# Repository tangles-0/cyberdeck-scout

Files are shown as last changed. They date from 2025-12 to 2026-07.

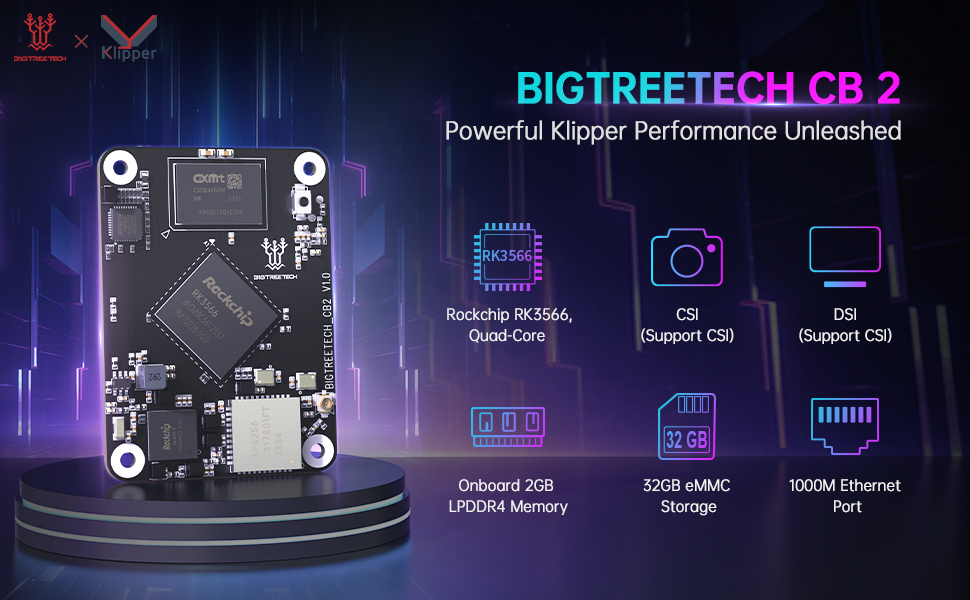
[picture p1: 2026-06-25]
Display Overlays/dsi-bigtreetech-cb2/wallpaper.jpg

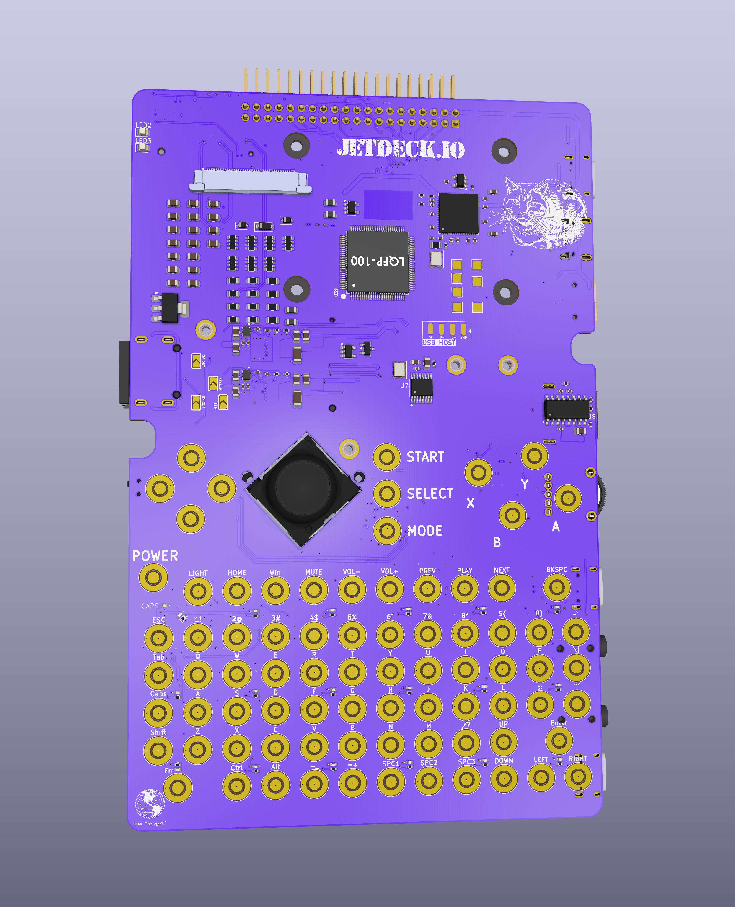
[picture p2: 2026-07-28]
PCB/cyberdeck/cyberdeck-a.png

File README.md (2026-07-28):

## JetDeck SCOUT - https://jetdeck.io

# Scout Cyberdeck

Repository contents:

- PCB design files
  - `/PCB/cyberdeck` current working PCB design file
  - `/PCB/cyberdeck-r1|r2 etc` snapshot of files sent for production
- USB PD sink EEPROM flash
  - `/Firmware/TPS25751` EEPROM images for the TPS25751 PD front-end
- Gamepad / mouse firmware
  - `/Firmware/gamepad-touch` RP2040 mbed sketch for the gamepad. reports HID Mouse, HID Gamepad, HID Touch Interface, and HID Battery to the host
- Keyboard firmware
  - `/Firmware/qmk/` drop this into your `qmk_firmware` folder and run `qmk flash -kb rii/518bt -km default` to flash the keyboard
- Bring-up / test / QA jig (PCB files TBA) and firmware
  - `/Firmware/esp32-bringup` 
- 3D casing design files
  - `/Casing CAD`
- Datasheets
  - `/Datasheets` for the major components used
- Display Overlays
  - `/Display Overlays` overlays for the DSI display used in testing
- Software
  - `/Software` will be used if any custom software is written

// #ifndef PIN_PA0
// #define PIN_PA0 11
// #endif
// #ifndef PIN_PA1
// #define PIN_PA1 8
// #endif
// #ifndef PIN_PA2
// #define PIN_PA2 9
// #endif
// #ifndef PIN_PA3
// #define PIN_PA3 10
// #endif
// #ifndef PIN_PA4
// #define PIN_PA4 0
// #endif
// #ifndef PIN_PA5
// #define PIN_PA5 1
// #endif
// #ifndef PIN_PA6
// #define PIN_PA6 2
// #endif
// #ifndef PIN_PA7
// #define PIN_PA7 3
// #endif
// #ifndef PIN_PB0
// #define PIN_PB0 7
// #endif
// #ifndef PIN_PB1
// #define PIN_PB1 6
// #endif
// #ifndef PIN_PB2
// #define PIN_PB2 5
// #endif
// #ifndef PIN_PB3
// #define PIN_PB3 4
// #endif

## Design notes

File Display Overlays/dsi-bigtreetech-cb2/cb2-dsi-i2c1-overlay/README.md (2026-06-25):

# CB2 DSI1 I2C1 Display Overlay

This overlay enables the BIGTREETECH CB2 DSI1 display path while moving the Raspberry Pi 7-inch display control MCU and FT5406-compatible touch controller from the stock CB2 I2C2 pins to I2C1.

Use this for carrier boards where the display I2C lines are:

- SCL: CM pin 35, `GPIO0_B3`
- SDA: CM pin 26, `GPIO0_B4`

The overlay was tested on the CB2 Debian 12 kernel `6.1.115-btt-rk35xx`.

Expected I2C devices after boot:

- `1-0045`: display MCU/backlight
- `1-0038`: FT5406-compatible touch controller

## Files

- `cb2-dsi-i2c1-rpi7.dts`: editable device tree overlay source.
- `cb2-dsi-i2c1-rpi7.dtbo`: compiled overlay to install on the CB2.
- `install.sh`: installs the overlay and updates `/boot/armbianEnv.txt`.

## Install

Copy this folder to the CB2, then run:

```bash
cd cb2-dsi-i2c1-overlay
sudo ./install.sh
sudo reboot
```

The installer:

- Creates `/boot/overlay-user/`.
- Copies `cb2-dsi-i2c1-rpi7.dtbo` into it.
- Backs up `/boot/armbianEnv.txt`.
- Clears `overlays=` so the stock `dsi` overlay does not also enable the wrong I2C2 nodes.
- Sets `user_overlays=cb2-dsi-i2c1-rpi7`.

The relevant `/boot/armbianEnv.txt` lines should look like:

```ini
overlays=
user_overlays=cb2-dsi-i2c1-rpi7
```

## Build

If you edit the source, rebuild the compiled overlay with:

```bash
dtc -@ -I dts -O dtb -o cb2-dsi-i2c1-rpi7.dtbo cb2-dsi-i2c1-rpi7.dts
```

Install `device-tree-compiler` first if `dtc` is missing.

## Verify

After reboot:

```bash
ls /sys/class/drm
dmesg | grep -Ei 'dsi|panel|i2c|touch|raspberry'
```

You should see a DSI connector such as `card0-DSI-1`, and the old failing probes on I2C2 (`2-0045`, `2-0038`) should be gone.

Touch should appear as an input device:

```bash
grep -E 'Name=|Handlers=' /proc/bus/input/devices
```

The working setup reports a device similar to `1-0038 generic ft5x06`.

## Rollback

If the board does not boot/display correctly, restore the backup from SSH or serial:

```bash
sudo cp /boot/armbianEnv.txt.pre-cb2-dsi-i2c1-rpi7 /boot/armbianEnv.txt
sudo reboot
```

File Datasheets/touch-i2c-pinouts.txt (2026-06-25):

Current driver / OLED display i2c pinout

1 SCL
2 SDA
3 INT
4 GND
5 VDD
6 RST

Large pitch display i2c pinout

1 GND
2 SDA
3 SCL
4 RST
5 INT
6 VDD3.3V

blk grn blu yel wht red

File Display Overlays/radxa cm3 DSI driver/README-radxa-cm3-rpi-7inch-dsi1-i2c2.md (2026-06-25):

# Radxa CM3 Raspberry Pi 7-inch DSI Overlay

This folder contains patched Radxa CM3 overlays for a Raspberry Pi 7-inch-touch-compatible DSI panel on a CM5-wired carrier board.

The shipped CM3 `disp1` overlay enables `dsi1`, but places the panel control/touch devices on `i2c0`. These patched overlays move the control/touch bus to `i2c2` using the CM3 `i2c2m1_xfer` pinmux.

Recommended overlay for the DSI panel:

```text
radxa-cm3-rpi-cm4-7inch-touchscreen-disp1-i2c2.dtbo
```

Experimental HDMI-enabled overlay:

```text
radxa-cm3-rpi-cm4-7inch-touchscreen-disp1-i2c2-hdmi.dtbo
```

The HDMI-enabled overlay leaves HDMI connected at the kernel/DRM level, with HDMI routed via `vp0` and DSI routed via `vp1`. On the tested Radxa CM3 image, KDE/X11 reports two extended displays, but both physical panels show the same scanout content. Treat this overlay as experimental or mirrored-output only, not a confirmed independent dual-display setup.

## Install

Copy the overlay to the Radxa:

```sh
scp radxa-cm3-rpi-cm4-7inch-touchscreen-disp1-i2c2.dtbo radxa@192.168.1.129:/tmp/
```

Install it into `/boot/dtbo`:

```sh
ssh radxa@192.168.1.129
sudo install -o root -g root -m 0644 /tmp/radxa-cm3-rpi-cm4-7inch-touchscreen-disp1-i2c2.dtbo /boot/dtbo/
```

Back up the boot config:

```sh
stamp=$(date +%Y%m%d-%H%M%S)
sudo cp -a /etc/default/u-boot "/etc/default/u-boot.bak.$stamp"
sudo cp -a /boot/extlinux/extlinux.conf "/boot/extlinux/extlinux.conf.bak.$stamp"
```

Add this to `/etc/default/u-boot`:

```sh
U_BOOT_FDT_OVERLAYS="radxa-cm3-rpi-cm4-7inch-touchscreen-disp1-i2c2.dtbo"
```

Regenerate the bootloader config and reboot:

```sh
sudo u-boot-update
sudo reboot
```

## Verify

After reboot, these checks should show the panel bound on `dsi1` and the touch/control devices bound on `i2c2`:

```sh
tr '\0' '\n' </proc/device-tree/dsi@fe070000/status
tr '\0' '\n' </proc/device-tree/i2c@fe5b0000/status
ls /sys/bus/i2c/devices/2-0030 /sys/bus/i2c/devices/2-0038 /sys/bus/i2c/devices/2-0045
cat /sys/class/drm/card0-DSI-1/status
cat /sys/class/drm/card0-DSI-1/modes
grep -A8 'Name="fts_ts"' /proc/bus/input/devices
```

Expected results:

```text
dsi1 status: okay
i2c2 status: okay
DRM connector: card0-DSI-1 connected
DSI mode: 800x480
touch input: fts_ts on i2c-2 address 0x38
panel MCU: rockpi_mcu on i2c-2 address 0x45
optional touch/client node: chipone_icn8505 on i2c-2 address 0x30
```

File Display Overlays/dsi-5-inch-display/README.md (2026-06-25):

# 5-inch DSI ILI9881C Overlay

This directory contains the working overlay for the 5-inch 720x1280 DSI display on a Raspberry Pi CM5.
Sold as "Surenoo" brand on Aliexpress: https://www.aliexpress.com/item/1005006436051194.html
Listed as a WKS50HD002-WCT from supplier WKS Technology Co., LTD according to datasheet

## Files

- `ili9881c.dtbo` - compiled overlay to copy onto the Pi
- `ili9881c-overlay.dts` - source used to build the overlay

## Install

Copy the compiled overlay to:

```bash
sudo cp ili9881c.dtbo /boot/firmware/overlays/ili9881c.dtbo
```

Then enable it in `/boot/firmware/config.txt`:

```ini
[cm5]
dtoverlay=ili9881c
```

Keep other DSI panel overlays disabled at the same time, for example:

```ini
#dtoverlay=vc4-kms-dsi-7inch,dsi1
#dtoverlay=vc4-kms-dsi-ili9881-7inch
```

## Build

```bash
dtc -@ -I dts -O dtb -o ili9881c.dtbo ili9881c-overlay.dts
```

The known-good panel compatible is:

```dts
compatible = "crystalfontz,cfaf7201280a0_050tx";
```

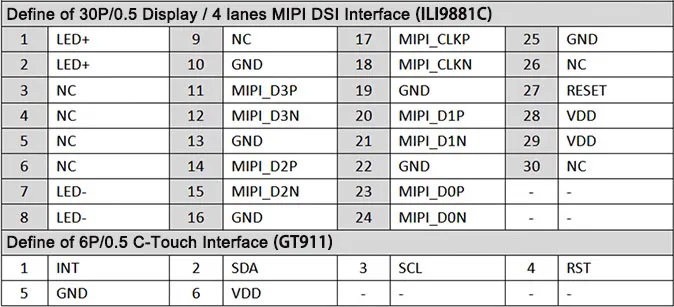
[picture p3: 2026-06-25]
Display Overlays/dsi-5-inch-display/5inch display pinout.png

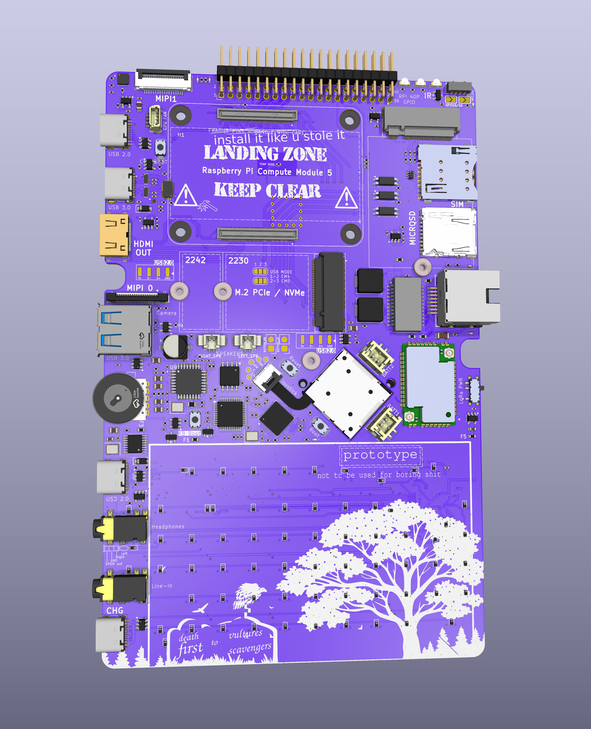
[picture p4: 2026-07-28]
PCB/cyberdeck/cyberdeck-b.png

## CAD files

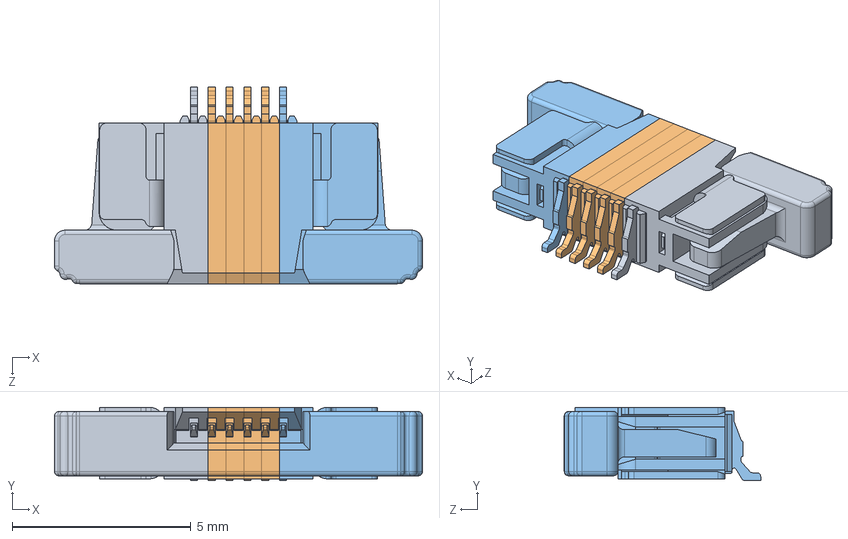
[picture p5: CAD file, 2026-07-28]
PCB-Resources/models/F32Q-1A7H1-11006--3DModel-STEP-56544.STEP
10.3 x 2.05 x 5.50 mm
F32Q_L.STEP
F32Q_M.STEP x 4
F32Q_R.STEP

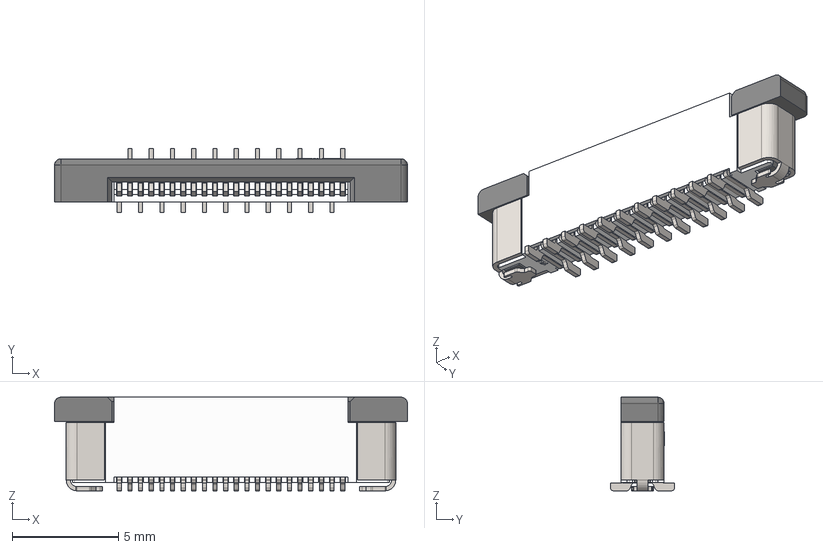
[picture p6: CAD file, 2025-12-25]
PCB/cyberdeck-compact/EASYEDA_MODELS/FPC-SMD_22P-P1.00_AFC11-S22ICC-00.step
16.6 x 3.00 x 4.40 mm

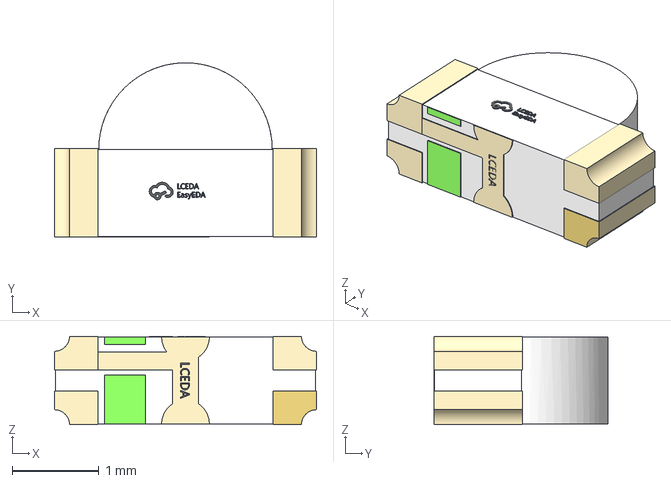
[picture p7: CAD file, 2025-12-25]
PCB/usb-cart/EASYEDA_MODELS/LED-ARRAY-SMD_3P-L3.0-W2.0-H1.0.step
3.02 x 2.01 x 1.02 mm

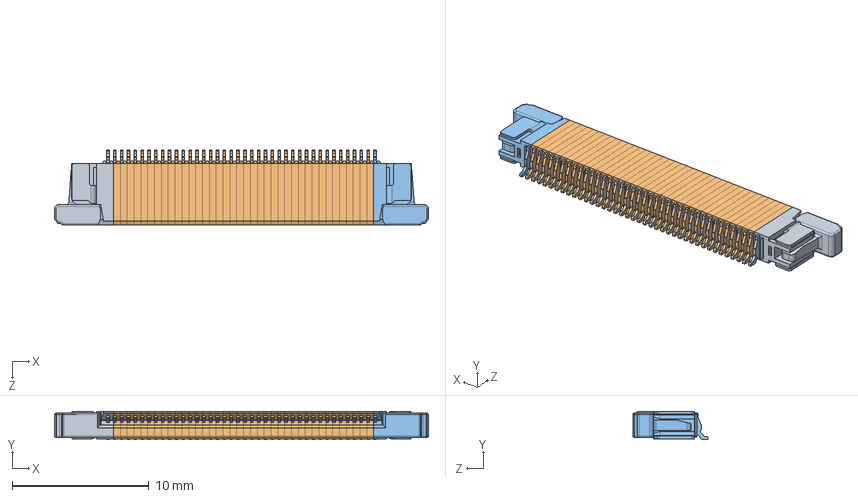
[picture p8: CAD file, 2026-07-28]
PCB-Resources/models/F32Q-1A7H1-11040--3DModel-STEP-56544.STEP
27.3 x 2.05 x 5.50 mm
F32Q_L.STEP
F32Q_M.STEP x 38
F32Q_R.STEP

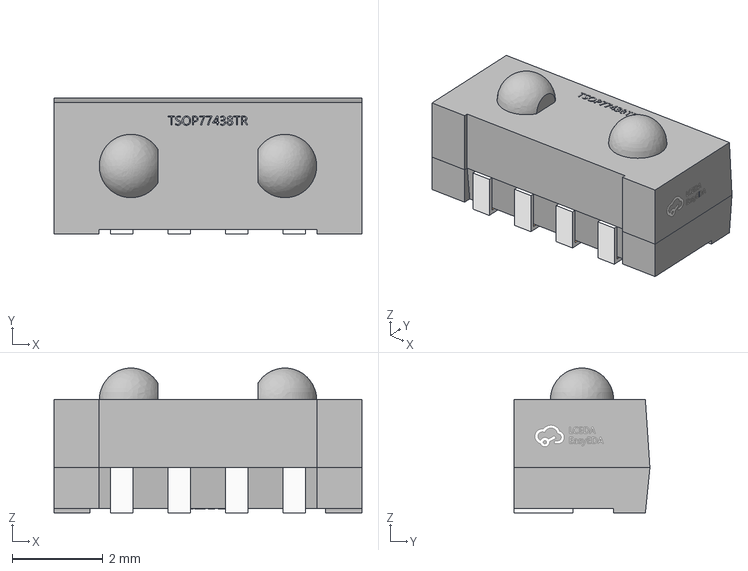
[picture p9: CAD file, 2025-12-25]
PCB/cyberdeck-compact/EASYEDA_MODELS/SENSOR-SMD_TSOP77438TR.step
6.80 x 3.00 x 3.20 mm

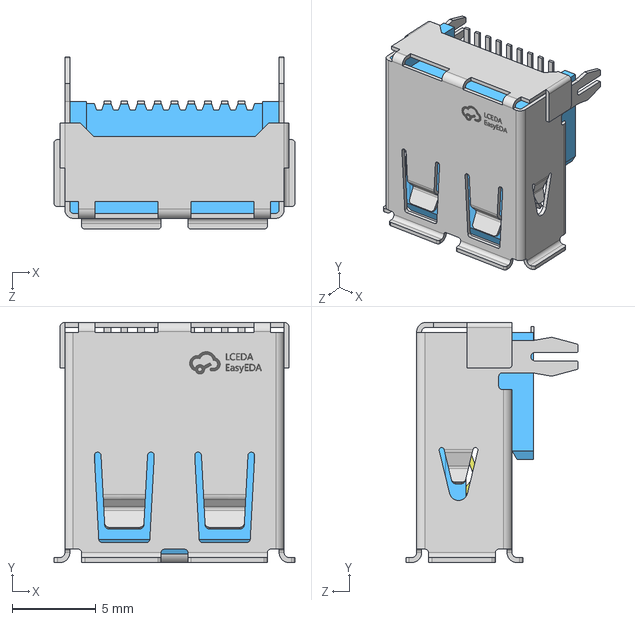
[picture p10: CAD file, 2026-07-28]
PCB-Resources/models/USB-3.0-SMD_U-A-39DS-Y-1.step
14.4 x 14.4 x 10.3 mm

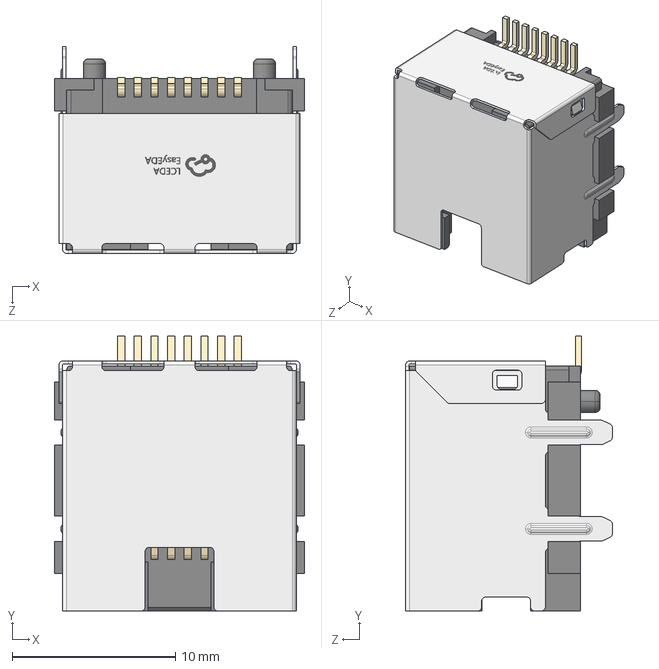
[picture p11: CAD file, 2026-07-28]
PCB-Resources/models/RJ45-SMD_RJ-064.step
15.3 x 16.8 x 12.7 mm

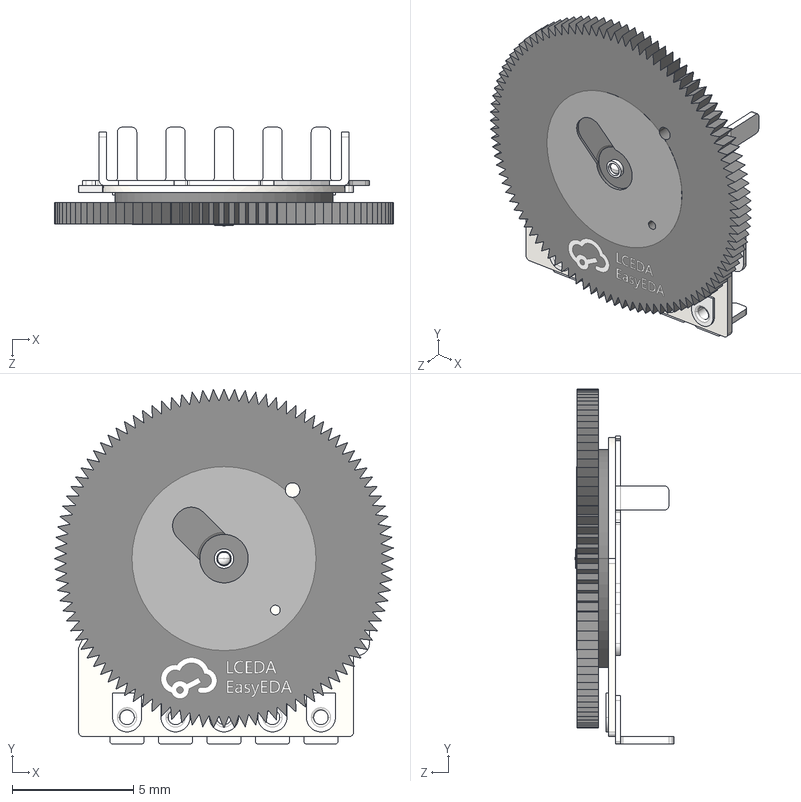
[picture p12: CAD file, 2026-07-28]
PCB-Resources/models/RES-TH_RK10J12E002L.step
14.0 x 14.6 x 4.07 mm

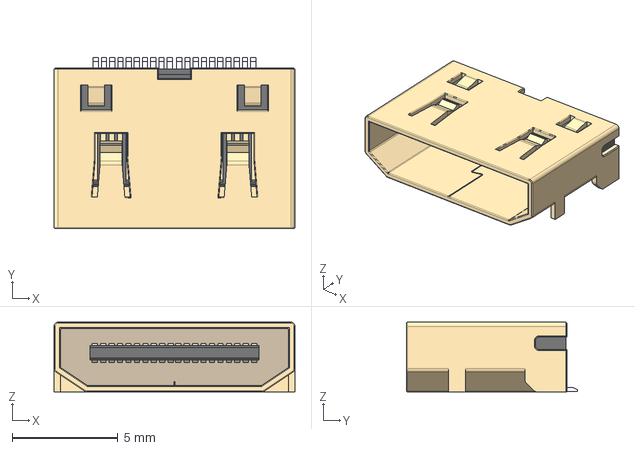
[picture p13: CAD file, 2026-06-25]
PCB-Resources/models/Mini_HDMI_Type-C.step
11.4 x 8.10 x 3.30 mm

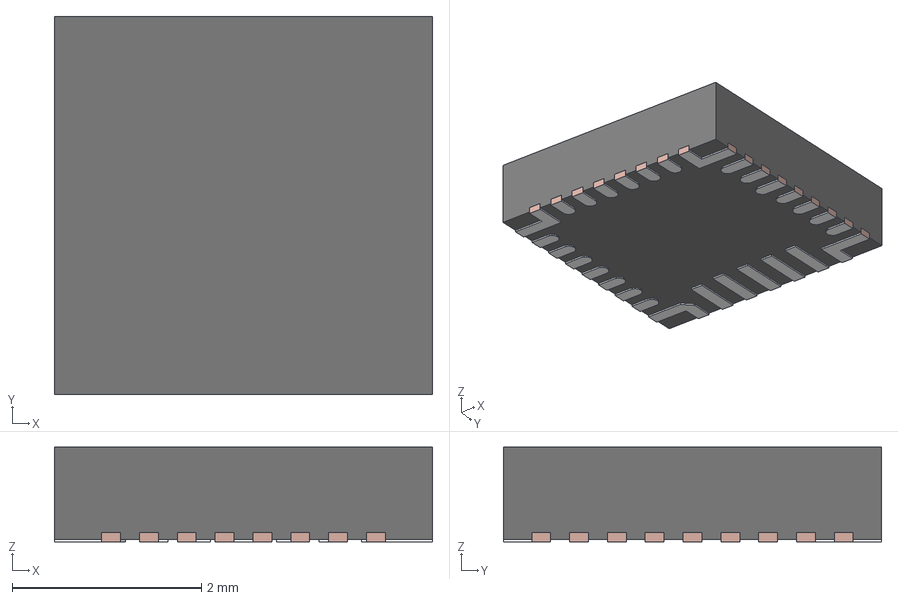
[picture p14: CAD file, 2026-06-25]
PCB-Resources/models/RQM0029A.stp
4.00 x 4.00 x 1.00 mm
FRAME
MOLD

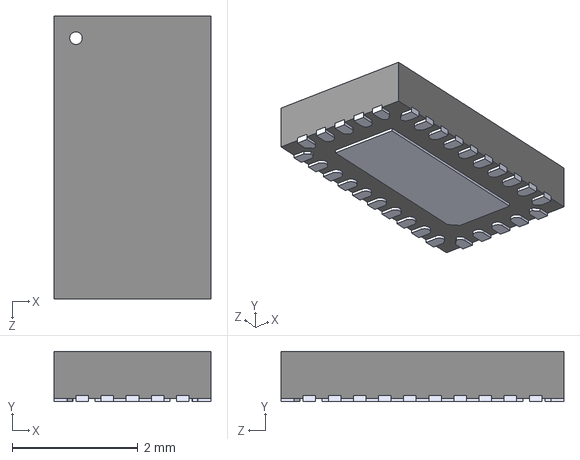
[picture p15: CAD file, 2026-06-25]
PCB-Resources/models/HD3SS3220IRNHT.step
2.50 x 0.8 x 4.50 mm

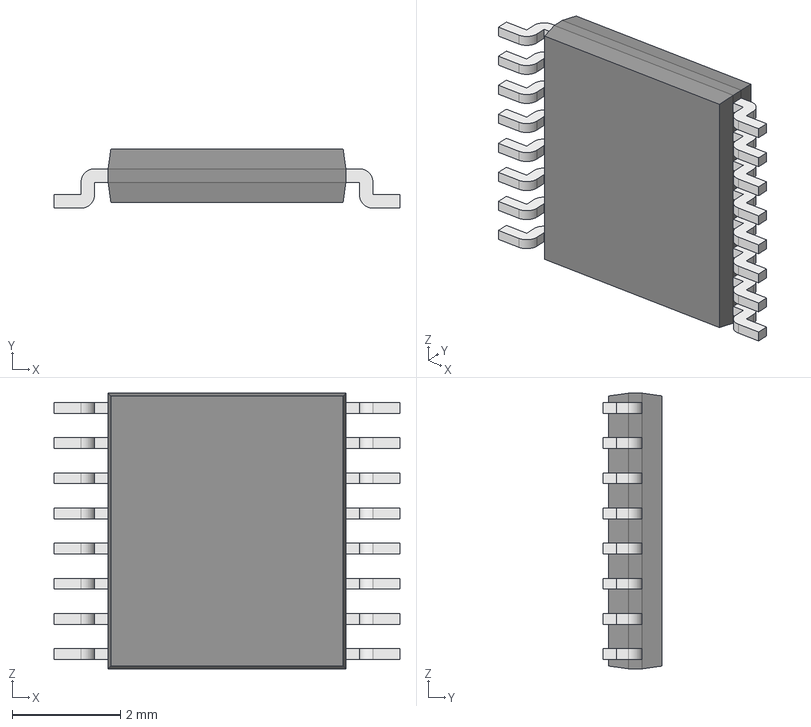
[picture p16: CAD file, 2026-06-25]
PCB-Resources/models/S-8254AAWFT-TB-G.step
6.40 x 1.10 x 5.10 mm
Body001 (Mirror #1) x 8
XY-plane x 12
X-axis x 12

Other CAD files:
PCB-Resources/models/1-2199119-5.step
PCB-Resources/models/1000base-t-magnetics.stp
PCB-Resources/models/10164227-1001a1rlf.stp
PCB-Resources/models/10164227-1004A1RLF.step
PCB-Resources/models/2-1734839-0.stp
PCB-Resources/models/2199119-3.step
PCB-Resources/models/2199230-3.stp
PCB-Resources/models/4_3inch-dsi-lcd-V1.stp
PCB-Resources/models/7498111120R--3DModel-STEP-56544.STEP
PCB-Resources/models/AFC01-S40FCA-00.step
PCB-Resources/models/AFC07-S05FCA-00.stp
PCB-Resources/models/AFC07-S22FCA-00.stp
PCB-Resources/models/AFC07-S30FCA-00.stp
PCB-Resources/models/B2B-PH-SM4-TB--3DModel-STEP-418109.STEP
PCB-Resources/models/BM04B-SRSS-TB.step
PCB-Resources/models/BQ25792RQMR.step
PCB-Resources/models/BQ76905RGRR.step
PCB-Resources/models/DM3AT-SF-PEJM5.step
PCB-Resources/models/FPC-5.stp
PCB-Resources/models/FTE-121-01-G-DH-K.stp
PCB-Resources/models/HR961160C.step
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

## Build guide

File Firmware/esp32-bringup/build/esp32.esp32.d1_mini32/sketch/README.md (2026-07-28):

#line 1 "/media/nvme_raid0/mPC/cyberdeck-scout/Firmware/esp32-bringup/README.md"
# Unified ESP32 service

Single sketch combining:

- **BQ76905** — negotiated I2C control with the ATtiny404. The Tiny owns the BQ by default, then hands controller role to the ESP when it detects the ESP discovery target.
- **TPS25751 + BQ25792** — JSON snapshot on **I2Ct** only (TPS as I2C target + BQ25792). The ESP does **not** use I2Cc for monitoring; I2Cc is controller-side on your board and is not where TPS status is read.
- **Flashing** — browser upload to LittleFS staging (`/stg_eeprom.bin`, `/stg_attiny.bin`), then background jobs:
  - **EEPROM** on **I2Cc** (AT24). **Power TPS25751 down** before starting — firmware temporarily remaps the second hardware I2C peripheral from I2Ct pins to I2Cc pins for the duration of the job, then restores I2Ct for `/api/charger`.
  - **ATtiny404** over UART-mode **UPDI** (same framing ideas as `jtag2updi`).

## I2C wiring model

| Bus | Role |
|---|---|
| First `TwoWire(0)` | BQ76905 / ATtiny404 shared bus. ESP starts as discovery target `ESP_BQ_DISCOVERY_ADDR`, then becomes controller after Tiny handoff |
| Second `TwoWire(1)` @ **I2Ct** pins | TPS25751 target + BQ25792 — **monitoring** |
| Same peripheral @ **I2Cc** pins | EEPROM programming **only** while TPS is off |

Current defaults use GPIO **25/26** for **I2Ct** charger monitoring and GPIO **18/19** for the optional **I2Cc** EEPROM-flash remap. Adjust **`PIN_I2C_I2CT_*`** and **`PIN_I2C_I2CC_*`** in [config.h](config.h) to match your wiring before building.

## Configure before build

Edit **[config.h](config.h)**:

- `WIFI_SSID` / `WIFI_PASS`
- `PIN_I2C_BQ_*` — shared BQ76905 / ATtiny404 bus. Default firmware starts the ESP as an I2C discovery target at `0x42`; after handoff, the ESP becomes BQ controller and pings the Tiny target at `0x43`.
- `PIN_I2C_I2CT_*` — charger / PD monitor (TPS + BQ25792).
- `PIN_I2C_I2CC_*` — EEPROM (flash job only).
- `PIN_UPDI_RX` / `PIN_UPDI_TX` — jtag2updi-style UPDI wiring: RX direct to target UPDI, TX to target UPDI through a series resistor; **115200 8E2** after double-break by default.

## Build / upload

Arduino IDE or CLI, ESP32 core, board such as **ESP32 Dev Module** (`esp32:esp32:esp32`).

Partition scheme: default usually suffices; LittleFS is created with `LittleFS.begin(true)` on first boot.

## Web UI

Open device IP in a browser. Tabs:

1. **BQ76905** — telemetry + tiles from direct ESP reads after handoff. Before handoff, buttons are disabled because the Tiny still owns BQ configuration and balancing. Tiny probes the ESP every ~3 s, tells it to become controller, then listens as a target for 500 ms ESP pings. The first ping gets an 8 s startup grace window; after pings are established, a >1 s miss returns the Tiny to BQ master mode, reconfigures the BQ, and resumes ESP discovery.
2. **Charger / PD** — formatted `/api/charger` JSON (or a suspended message while an EEPROM job holds the bus).
3. **Flash** — upload EEPROM / ATTiny binaries, then **Start**; poll `/api/flash/status`.

## Limitations

- **ATTiny UPDI** path is a focused application programmer (no Arduino-IDE JTAG2 bridge, no fuse writes). Target is **ATtiny404** (4 KB flash) via `ATTINY_FLASH_*` in `config.h`. Wire the ESP32 like the working Pro Micro setup: RX direct to the ATtiny UPDI pin and TX through the resistor. On enter-prog failure, `/api/flash/status` includes `updi_asi_status` (raw `ASI_System_Status`; `0xFF` usually means no UPDI reply).
- During EEPROM programming the charger tab may show `charger_monitor_suspended` — normal until the job finishes and I2Ct is restored.

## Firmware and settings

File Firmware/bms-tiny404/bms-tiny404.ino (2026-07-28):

// ATtiny404 BQ76905 host: configuration, power control, indicators, and host cell balancing.
// Requires megaTinyCore in Arduino IDE or arduino-cli.
// I2C to the BQ is bit-banged on PA1/PA2: the 404 (tinyAVR 0-series) has no
// alternate TWI pin position, and its hardware TWI pins (PB0/PB1) drive LEDs.

#define DEBUG 1
#define ENABLE_SHIP_BUTTON 0

// test swaps
static const uint8_t LED_PIN = PIN_PB3;
static const uint8_t BATT_LEVEL1_LED_PIN = PIN_PA4;

// rev 1b layout
static const uint8_t PWR_BUTTON_PIN = PIN_PA5;
static const uint8_t SHIP_BUTTON_PIN = PIN_PA6;
static const uint8_t PWR_CONTROL_PIN = PIN_PA3;
//static const uint8_t LED_PIN = PIN_PA4;
static const uint8_t CM5_SOFT_PWR_OUT = PIN_PA7;

//static const uint8_t BATT_LEVEL1_LED_PIN = PIN_PB3;
static const uint8_t BATT_LEVEL2_LED_PIN = PIN_PB2;
static const uint8_t BATT_LEVEL3_LED_PIN = PIN_PB1;
static const uint8_t BATT_LEVEL4_LED_PIN = PIN_PB0;

// BQ7690x I2C address
static const uint8_t BQ_ADDR = 0x08;

// Subcommand and data registers
static const uint8_t REG_SUBCMD = 0x3E;
static const uint8_t REG_SUBCMD_DATA = 0x60;
static const uint8_t REG_SAFETY_STATUS_A = 0x03;
static const uint8_t REG_BATTERY_STATUS = 0x12;
static const uint8_t REG_ALARM_RAW_STATUS = 0x64;
// static const uint8_t REG_FET_CONTROL = 0x68;
// static const uint8_t REGOUT_CONTROL = 0x69;
// static const uint8_t REGOUT_REG_EN = (1u << 3);

// Command-only subcommands
static const uint16_t SET_CFGUPDATE = 0x0090;
static const uint16_t EXIT_CFGUPDATE = 0x0092;
static const uint16_t DEEPSLEEP = 0x000F;
static const uint16_t EXIT_DEEPSLEEP = 0x000E;
#if ENABLE_SHIP_BUTTON
static const uint16_t SHUTDOWN = 0x0010;
#endif
// static const uint16_t FET_ENABLE = 0x0022;
// static const uint16_t SLEEP_DISABLE = 0x009A; // not needed - sleep mode is autonomous and desirable.

// Host-controlled balancing active-cells subcommand (requires payload bitmask).
// Required to be re-issued every ~18s; BQ aborts after ~20s for safety.
static const uint16_t START_BALANCE = 0x0083; 

// Configuration register addresses
static const uint16_t VcellMode = 0x901B;
static const uint16_t DefaultAlarmMask = 0x901C;
static const uint16_t FETOptions = 0x901E;
static const uint16_t EnabledProtectionsA = 0x9024;
static const uint16_t EnabledProtectionsB = 0x9025;
static const uint16_t BalancingConfiguration = 0x9020;
static const uint16_t BalancingMinTempThreshold = 0x9021;
static const uint16_t BalancingMaxTempThreshold = 0x9022;
static const uint16_t BalancingMaxInternalTemp = 0x9023;
static const uint16_t CellUndervoltageProtectionThreshold = 0x902E;
static const uint16_t CellUndervoltageProtectionDelay = 0x9030;
static const uint16_t CellUndervoltageProtectionRecoveryHysteresis = 0x9031;
static const uint16_t CellOvervoltageProtectionThreshold = 0x9032;
static const uint16_t CellOvervoltageProtectionDelay = 0x9034;
static const uint16_t CellOvervoltageProtectionRecoveryHysteresis = 0x9035;

// Cell voltage registers (for host balancing decisions only)
static const uint8_t REG_CELL1_VOLTAGE = 0x14;
static const uint8_t REG_CELL2_VOLTAGE = 0x16;

// Button, power-control, and indicator timings (ms)
static const uint16_t SHORT_PRESS_MIN_MS = 80;
static const uint16_t LONG_PRESS_MS = 3000;
static const uint16_t CM5_SOFT_PRESS_MS = 300;
static const uint16_t POWER_SOFT_PRESS_ARM_MS = 15000;
static const uint8_t POWER_LED_IDLE_BREATH_STEP_MS = 18;
static const uint8_t FAST_LED_BREATH_STEP_MS = 5;
static const uint16_t STATUS_LED_BLINK_MS = 120;
static const uint16_t SHIP_LED_BLINK_MS = 100;
static const uint16_t PROTECTION_LED_MIN_MS = 3000;

static const uint8_t POWER_LED_ON_DUTY = 180;
static const uint8_t POWER_LED_BREATH_MIN_DUTY = 5;
static const uint8_t POWER_LED_BREATH_MAX_DUTY = 100;
static const uint8_t BATT_LED_BREATH_MIN_DUTY = 5;
static const uint8_t BATT_LED_BREATH_MAX_DUTY = 180;

static const uint16_t ALARM_RAW_CB = (1u << 8);
static const uint8_t SAFETY_STATUS_A_CUV = (1u << 6);
static const uint8_t SAFETY_STATUS_A_COV = (1u << 7);

// 2S Li-ion display thresholds. LED1 is the low/end-of-pack indicator.
static const uint16_t CELL_UV_THRESHOLD_MV = 3000;
static const uint16_t CELL_OV_THRESHOLD_MV = 4200;
static const uint16_t LOW_BATT_WARN_CELL_MV = 3150;
static const uint16_t BATT_LED1_PACK_MV = 6100;
static const uint16_t BATT_LED2_PACK_MV = 6900;
static const uint16_t BATT_LED3_PACK_MV = 7400;
static const uint16_t BATT_LED4_PACK_MV = 7900;

// Host balancing poll interval
static const uint16_t BALANCE_POLL_PERIOD_MS = 100;

// Host balancing (START_BALANCE): not gated on charge current or device power state.
// Balance whichever cell is higher once the voltage and imbalance thresholds are met.
static const uint16_t BALANCE_MIN_ANY_CELL_MV = 3100;
static const uint16_t BALANCE_MIN_DELTA_MV = 20;
static const uint16_t BALANCE_RETRIGGER_MS = 18000; // BQ balancing command timeout is about 20s
static const uint16_t BQ_CONFIG_RETRY_MS = 1000;

#if DEBUG
static void debugBegin() {
  pinModeFast(BATT_LEVEL2_LED_PIN, OUTPUT);
  USART0.BAUD = (uint16_t)((4UL * F_CPU) / 115200);
  USART0.CTRLC = USART_CHSIZE_8BIT_gc;
  USART0.CTRLB = USART_TXEN_bm;
}

static void debugChar(char c) {
  while (!(USART0.STATUS & USART_DREIF_bm)) {}
  USART0.TXDATAL = c;
}

static void debugUint(uint16_t value) {
  char buf[5];
  uint8_t i = 0;
  do {
    buf[i++] = (char)('0' + value % 10);
    value /= 10;
  } while (value != 0);
  while (i != 0) {
    debugChar(buf[--i]);
  }
}

static void debugNl() {
  debugChar('\n');
}
#else
#define debugBegin() do {} while (0)
#define debugChar(c) do {} while (0)
#define debugUint(v) do {} while (0)
#define debugNl() do {} while (0)
#endif

static uint8_t checksum(const uint8_t *data, uint8_t len) {
  uint16_t sum = 0;
  for (uint8_t i = 0; i < len; i++) {
    sum += data[i];
  }
  return (uint8_t)(0xFF & ~sum);
}

// Bit-banged open-drain I2C master on PA1 (SDA) / PA2 (SCL).
// The ATtiny404 is a tinyAVR 0-series part: its hardware TWI exists only on
// PB0/PB1 (no PORTMUX alternate position — that is a 1-series feature), but
// the board routes the BQ bus to PA1/PA2. External 10K pullups; lines are
// driven low by flipping DIR (OUT stays 0), released by tri-stating.
static const uint8_t I2C_SDA_bm = (1 << 1); // PA1
static const uint8_t I2C_SCL_bm = (1 << 2); // PA2

// Error codes kept compatible with Wire/debug protocol:
// 0 ok, 2 address NACK, 3 data NACK, 5 clock-stretch timeout.
static uint8_t lastI2cError = 0;

static inline void i2cDelay() { delayMicroseconds(4); } // ~100 kHz

static bool i2cSclRelease() {
  VPORTA.DIR &= ~I2C_SCL_bm;
  // Allow slave clock stretching, with a timeout so a dead bus can't hang us.
  for (uint16_t i = 0; i < 10000; i++) {
    if (VPORTA.IN & I2C_SCL_bm) {
      return true;
    }
  }
  lastI2cError = 5;
  return false;
}

static void i2cStart() {
  VPORTA.DIR &= ~I2C_SDA_bm;
  i2cSclRelease();
  i2cDelay();
  VPORTA.DIR |= I2C_SDA_bm;  // SDA low while SCL high = START
  i2cDelay();
  VPORTA.DIR |= I2C_SCL_bm;
}

static void i2cStop() {
  VPORTA.DIR |= I2C_SDA_bm;
  i2cDelay();
  i2cSclRelease();
  i2cDelay();
  VPORTA.DIR &= ~I2C_SDA_bm; // SDA released while SCL high = STOP
  i2cDelay();
}

// Returns true if the slave ACKed the byte.
static bool i2cWriteByte(uint8_t value) {
  for (uint8_t bit = 0; bit < 8; bit++) {
    if (value & 0x80) {
      VPORTA.DIR &= ~I2C_SDA_bm;
    } else {
      VPORTA.DIR |= I2C_SDA_bm;
    }
    value <<= 1;
    i2cDelay();
    if (!i2cSclRelease()) {
      return false;
    }
    i2cDelay();
    VPORTA.DIR |= I2C_SCL_bm;
  }

  VPORTA.DIR &= ~I2C_SDA_bm; // release for ACK bit
  i2cDelay();
  if (!i2cSclRelease()) {
    return false;
  }
  const bool acked = (VPORTA.IN & I2C_SDA_bm) == 0;
  i2cDelay();
  VPORTA.DIR |= I2C_SCL_bm;
  return acked;
}

static uint8_t i2cReadByte(bool ack) {
  uint8_t value = 0;
  VPORTA.DIR &= ~I2C_SDA_bm;
  for (uint8_t bit = 0; bit < 8; bit++) {
    i2cDelay();
    if (!i2cSclRelease()) {
      return 0xFF;
    }
    value = (uint8_t)(value << 1);
    if (VPORTA.IN & I2C_SDA_bm) {
      value |= 1;
    }
    i2cDelay();
    VPORTA.DIR |= I2C_SCL_bm;
  }

  if (ack) {
    VPORTA.DIR |= I2C_SDA_bm;
  }
  i2cDelay();
  if (!i2cSclRelease()) {
    return value;
  }
  i2cDelay();
  VPORTA.DIR |= I2C_SCL_bm;
  VPORTA.DIR &= ~I2C_SDA_bm;
  return value;
}

static void i2cInit() {
  VPORTA.OUT &= ~(I2C_SDA_bm | I2C_SCL_bm); // low when driven
  VPORTA.DIR &= ~(I2C_SDA_bm | I2C_SCL_bm); // released (pulled up) when idle
}

static uint8_t i2cWrite(uint8_t reg, const uint8_t *data, uint8_t len) {
  lastI2cError = 0;
  i2cStart();
  if (!i2cWriteByte((uint8_t)(BQ_ADDR << 1))) {
    if (lastI2cError == 0) {
      lastI2cError = 2;
    }
  } else if (!i2cWriteByte(reg)) {
    if (lastI2cError == 0) {
      lastI2cError = 3;
    }
  } else {
    for (uint8_t i = 0; i < len; i++) {
      if (!i2cWriteByte(data[i])) {
        if (lastI2cError == 0) {
          lastI2cError = 3;
        }
        break;
      }
    }
  }
  i2cStop();
  delay(2);
  return lastI2cError;
}

static bool i2cRead16(uint8_t reg, uint16_t *value) {
  lastI2cError = 0;
  i2cStart();
  if (!i2cWriteByte((uint8_t)(BQ_ADDR << 1)) || !i2cWriteByte(reg)) {
    if (lastI2cError == 0) {
      lastI2cError = 2;
    }
    i2cStop();
    return false;
  }

  i2cStart(); // repeated START
  if (!i2cWriteByte((uint8_t)((BQ_ADDR << 1) | 1))) {
    if (lastI2cError == 0) {
      lastI2cError = 2;
    }
    i2cStop();
    return false;
  }

  const uint8_t lsb = i2cReadByte(true);
  const uint8_t msb = i2cReadByte(false);
  i2cStop();
  if (lastI2cError != 0) {
    return false;
  }
  *value = (uint16_t)(msb << 8) | lsb;
  return true;
}

static uint8_t sendSubcommand(uint16_t cmd) {
  uint8_t buf[2] = { (uint8_t)(cmd & 0xFF), (uint8_t)(cmd >> 8) };
  return i2cWrite(REG_SUBCMD, buf, sizeof(buf));
}

static void writeConfig8(uint16_t addr, uint8_t value) {
  uint8_t payload[3] = {
    (uint8_t)(addr & 0xFF),
    (uint8_t)(addr >> 8),
    value
  };
  uint8_t cks = checksum(payload, sizeof(payload));
  uint8_t meta[2] = { cks, 0x05 };
  i2cWrite(REG_SUBCMD, payload, sizeof(payload));
  i2cWrite(REG_SUBCMD_DATA, meta, sizeof(meta));
}

static void writeConfig16(uint16_t addr, uint16_t value) {
  uint8_t payload[4] = {
    (uint8_t)(addr & 0xFF),
    (uint8_t)(addr >> 8),
    (uint8_t)(value & 0xFF),
    (uint8_t)(value >> 8)
  };
  uint8_t cks = checksum(payload, sizeof(payload));
  uint8_t meta[2] = { cks, 0x06 };
  i2cWrite(REG_SUBCMD, payload, sizeof(payload));
  i2cWrite(REG_SUBCMD_DATA, meta, sizeof(meta));
}

static bool bqCellBalancingActive = false;
static bool bqReadValid = false;
static uint16_t latestBatteryStatus = 0;
static bool bqConfigured = false;
static uint16_t latestCell1Mv = 0;
static uint16_t latestCell2Mv = 0;
static uint16_t protectionBlinkUntilMs = 0;
static uint8_t protectionBlinkFlags = 0;
static uint16_t lastBqConfigAttemptMs = 0;
#if DEBUG
static uint16_t lastDebugStatusMs = 0;
#endif

static bool devicePowerOn = false;
static uint16_t devicePowerOnStartedMs = 0;
static uint8_t powerLedBreathDuty = POWER_LED_BREATH_MIN_DUTY;
static int8_t powerLedBreathDirection = 1;
static uint16_t powerLedLastStepMs = 0;
static uint8_t battLedBreathDuty = BATT_LED_BREATH_MIN_DUTY;
static int8_t battLedBreathDirection = 1;
static uint16_t battLedLastStepMs = 0;
static uint16_t lastStatusBlinkMs = 0;
static bool statusBlinkOn = false;

static void writeActiveLowPwm(uint8_t pin, uint8_t duty) {
  analogWrite(pin, 255 - duty);
}

static uint8_t breathingDuty(uint8_t *duty, int8_t *direction, uint16_t *lastStepMs,
                             uint16_t now, uint8_t stepMs,
                             uint8_t minDuty, uint8_t maxDuty) {
  if ((uint16_t)(now - *lastStepMs) >= stepMs) {
    *lastStepMs = now;
    const int16_t nextDuty = (int16_t)(*duty) + *direction;
    if (nextDuty >= maxDuty) {
      *duty = maxDuty;
      *direction = -1;
    } else if (nextDuty <= minDuty) {
      *duty = minDuty;
      *direction = 1;
    } else {
      *duty = (uint8_t)nextDuty;
    }
  }
  return *duty;
}

static void releasePowerControl() {
  digitalWriteFast(PWR_CONTROL_PIN, HIGH);
  //pinModeFast(PWR_CONTROL_PIN, INPUT_PULLUP);
}

static void releaseCm5SoftPower() {
  digitalWriteFast(CM5_SOFT_PWR_OUT, HIGH);
  pinModeFast(CM5_SOFT_PWR_OUT, INPUT_PULLUP);
}

static void setBatteryLedsOff() {
  digitalWriteFast(BATT_LEVEL1_LED_PIN, HIGH);
#if !DEBUG
  digitalWriteFast(BATT_LEVEL2_LED_PIN, HIGH);
#endif
  digitalWriteFast(BATT_LEVEL3_LED_PIN, HIGH);
  digitalWriteFast(BATT_LEVEL4_LED_PIN, HIGH);
}

static void setDevicePower(bool on) {
  if (on) {
    if (!devicePowerOn) {
      devicePowerOnStartedMs = (uint16_t)millis();
    }
    pinModeFast(PWR_CONTROL_PIN, OUTPUT);
    digitalWriteFast(PWR_CONTROL_PIN, LOW);
    devicePowerOn = true;
    debugChar('P');
    debugChar('1');
    debugNl();
    return;
  }

  releasePowerControl();
  releaseCm5SoftPower();
  setBatteryLedsOff();
  devicePowerOn = false;
  debugChar('P');
  debugChar('0');
  debugNl();
}

static void startCm5SoftPowerPress() {
  if (!devicePowerOn) {
    return;
  }

  pinModeFast(CM5_SOFT_PWR_OUT, OUTPUT);
  digitalWriteFast(CM5_SOFT_PWR_OUT, LOW);
  delay(CM5_SOFT_PRESS_MS);
  releaseCm5SoftPower();
}

static void powerLedTask() {
  const uint16_t now = (uint16_t)millis();

  if (bqCellBalancingActive) {
    writeActiveLowPwm(LED_PIN, breathingDuty(&powerLedBreathDuty, &powerLedBreathDirection,
                                             &powerLedLastStepMs, now, FAST_LED_BREATH_STEP_MS,
                                             POWER_LED_BREATH_MIN_DUTY,
                                             POWER_LED_BREATH_MAX_DUTY));
  } else if (devicePowerOn) {
    writeActiveLowPwm(LED_PIN, POWER_LED_ON_DUTY);
  } else {
    writeActiveLowPwm(LED_PIN, breathingDuty(&powerLedBreathDuty, &powerLedBreathDirection,
                                             &powerLedLastStepMs, now, POWER_LED_IDLE_BREATH_STEP_MS,
                                             POWER_LED_BREATH_MIN_DUTY,
                                             POWER_LED_BREATH_MAX_DUTY));
  }
}

static uint8_t batteryLedCount() {
  if (!bqReadValid) {
    return 0;
  }

  const uint16_t packMv = latestCell1Mv + latestCell2Mv;
  if (packMv >= BATT_LED4_PACK_MV) {
    return 4;
  }
  if (packMv >= BATT_LED3_PACK_MV) {
    return 3;
  }
  if (packMv >= BATT_LED2_PACK_MV) {
    return 2;
  }
  if (packMv >= BATT_LED1_PACK_MV) {
    return 1;
  }
  return 0;
}

static bool lowBatteryWarningActive() {
  if (!bqReadValid) {
    return false;
  }

  return latestCell1Mv <= LOW_BATT_WARN_CELL_MV || latestCell2Mv <= LOW_BATT_WARN_CELL_MV;
}

static void batteryLedTask() {
  if (!devicePowerOn) {
    setBatteryLedsOff();
    return;
  }

  const uint16_t now = (uint16_t)millis();
  if ((uint16_t)(now - lastStatusBlinkMs) >= STATUS_LED_BLINK_MS) {
    lastStatusBlinkMs = now;
    statusBlinkOn = !statusBlinkOn;
  }
  if (protectionBlinkFlags != 0 && (int16_t)(now - protectionBlinkUntilMs) >= 0) {
    protectionBlinkFlags = 0;
  }
  const bool showUnderVoltage = (protectionBlinkFlags & SAFETY_STATUS_A_CUV) != 0;
  const bool showOverVoltage = (protectionBlinkFlags & SAFETY_STATUS_A_COV) != 0;

  if (showUnderVoltage || showOverVoltage) {
    digitalWriteFast(BATT_LEVEL1_LED_PIN, showUnderVoltage && statusBlinkOn ? LOW : HIGH);
#if !DEBUG
    digitalWriteFast(BATT_LEVEL2_LED_PIN, showUnderVoltage && statusBlinkOn ? LOW : HIGH);
#endif
    digitalWriteFast(BATT_LEVEL3_LED_PIN, showOverVoltage && statusBlinkOn ? LOW : HIGH);
    digitalWriteFast(BATT_LEVEL4_LED_PIN, showOverVoltage && statusBlinkOn ? LOW : HIGH);
    return;
  }

  if (lowBatteryWarningActive()) {
    writeActiveLowPwm(BATT_LEVEL1_LED_PIN, breathingDuty(&battLedBreathDuty, &battLedBreathDirection,
                                                        &battLedLastStepMs, now, FAST_LED_BREATH_STEP_MS,
                                                        BATT_LED_BREATH_MIN_DUTY,
                                                        BATT_LED_BREATH_MAX_DUTY));
#if !DEBUG
    digitalWriteFast(BATT_LEVEL2_LED_PIN, HIGH);
#endif
    digitalWriteFast(BATT_LEVEL3_LED_PIN, HIGH);
    digitalWriteFast(BATT_LEVEL4_LED_PIN, HIGH);
    return;
  }

  const uint8_t litCount = batteryLedCount();
  digitalWriteFast(BATT_LEVEL1_LED_PIN, litCount >= 1 ? LOW : HIGH);
#if !DEBUG
  digitalWriteFast(BATT_LEVEL2_LED_PIN, litCount >= 2 ? LOW : HIGH);
#endif
  digitalWriteFast(BATT_LEVEL3_LED_PIN, litCount >= 3 ? LOW : HIGH);
  digitalWriteFast(BATT_LEVEL4_LED_PIN, litCount >= 4 ? LOW : HIGH);
}

#if ENABLE_SHIP_BUTTON
static void enterShipMode() {
  sendSubcommand(SHUTDOWN);
  sendSubcommand(SHUTDOWN);

  setDevicePower(false);
  while (true) {
    digitalWriteFast(LED_PIN, LOW);
    delay(SHIP_LED_BLINK_MS);
    digitalWriteFast(LED_PIN, HIGH);
    delay(SHIP_LED_BLINK_MS);
  }
}
#endif

static bool bqPresent() {
  lastI2cError = 0;
  i2cStart();
  if (!i2cWriteByte((uint8_t)(BQ_ADDR << 1)) && lastI2cError == 0) {
    lastI2cError = 2;
  }
  i2cStop();
  return lastI2cError == 0;
}

static bool configureBq76905() {
  if (!bqPresent()) {
    // N<err> <pinlevels>: pinlevels bit0=SDA, bit1=SCL (3 = bus idle high).
    debugChar('N');
    debugUint(lastI2cError);
    debugChar(' ');
    debugChar((char)('0' + ((VPORTA.IN >> 1) & 0x03)));
    debugNl();
    return false;
  }

  sendSubcommand(SET_CFGUPDATE);
  delay(10);

  // 2S Li-ion defaults (VcellMode uses 0x00 for 2-series)
  writeConfig8(VcellMode, 0x02);

  // Enable autonomous FET control and allow CHG FET in SLEEP mode.
  // Bit map (Table 12-8): SLEEPCHG=bit4, SFET=bit3, FET_EN=bit2.
  writeConfig8(FETOptions, 0x1C);
  //writeConfig8(FETOptions, 0x04);

  // Enable only CUV/COV safety protections.
  // SafetyStatusA bit mapping uses COV=bit7, CUV=bit6 -> mask 0xC0.
  // Use 8-bit writes here because EnabledProtectionsA/B are 1-byte fields.
  writeConfig8(EnabledProtectionsA, 0xC0);
  writeConfig8(EnabledProtectionsB, 0x00);
  // Cell balancing settings:
  // - CB_NO_CMD=0 (allow CB_ACTIVE_CELLS host command), CBDLY=1ms (0x02 default)
  // - very permissive balance temperature window during bring-up
  writeConfig8(BalancingConfiguration, 0x02);
  writeConfig8(BalancingMinTempThreshold, 0xFF);
  writeConfig8(BalancingMaxTempThreshold, 0x00);
  writeConfig8(BalancingMaxInternalTemp, 110);
  // Debug-friendly: enable all alarm sources so AlarmStatus can latch SSA/SSB
  // and other events for host visibility.
  writeConfig16(DefaultAlarmMask, 0xFFFF);

  // Typical 2S Li-ion per-cell thresholds.
  // Thresholds are mV (I2). Delay/hysteresis are compact encoded fields (U1/H1).
  writeConfig16(CellUndervoltageProtectionThreshold, CELL_UV_THRESHOLD_MV);
  writeConfig8(CellUndervoltageProtectionDelay, 10);         // 10 ADSCAN intervals
  writeConfig8(CellUndervoltageProtectionRecoveryHysteresis, 2); // +100mV, autonomous recovery enabled

  writeConfig16(CellOvervoltageProtectionThreshold, CELL_OV_THRESHOLD_MV);
  writeConfig8(CellOvervoltageProtectionDelay, 10);          // 10 ADSCAN intervals
  writeConfig8(CellOvervoltageProtectionRecoveryHysteresis, 2); // -100mV, autonomous recovery enabled

  const bool ok = sendSubcommand(EXIT_CFGUPDATE) == 0;
  delay(100);
  debugChar(ok ? 'O' : 'E');
  debugNl();
  return ok;
}

static uint16_t lastBalancePollMs = 0;
static uint16_t lastBalanceCommandMs = 0;

/** Periodically read cell voltages and issue START_BALANCE when rules are met. */
static void hostBalanceTask() {
  const uint16_t now = (uint16_t)millis();
  if (!bqConfigured) {
    if ((uint16_t)(now - lastBqConfigAttemptMs) >= BQ_CONFIG_RETRY_MS) {
      lastBqConfigAttemptMs = now;
      bqConfigured = configureBq76905();
    }
    return;
  }

  if ((uint16_t)(now - lastBalancePollMs) < BALANCE_POLL_PERIOD_MS) {
    return;
  }
  lastBalancePollMs = now;

  uint16_t cell1Mv = 0;
  uint16_t cell2Mv = 0;
  if (!i2cRead16(REG_CELL1_VOLTAGE, &cell1Mv) ||
      !i2cRead16(REG_CELL2_VOLTAGE, &cell2Mv)) {
    bqReadValid = false;
    bqCellBalancingActive = false;
    bqConfigured = false;
    return;
  }
  bqReadValid = true;
  latestCell1Mv = cell1Mv;
  latestCell2Mv = cell2Mv;

  uint16_t regValue = 0;
  if (i2cRead16(REG_ALARM_RAW_STATUS, &regValue)) {
    bqCellBalancingActive = (regValue & ALARM_RAW_CB) != 0;
  }

  i2cRead16(REG_BATTERY_STATUS, &latestBatteryStatus);

  if (i2cRead16(REG_SAFETY_STATUS_A, &regValue)) {
    const uint8_t protectionA = (uint8_t)(regValue & 0xFF);
    if ((protectionA & (SAFETY_STATUS_A_CUV | SAFETY_STATUS_A_COV)) != 0) {
      protectionBlinkFlags |= protectionA & (SAFETY_STATUS_A_CUV | SAFETY_STATUS_A_COV);
      protectionBlinkUntilMs = now + PROTECTION_LED_MIN_MS;
    }
  }

  const bool anyCellAboveMin =
      (cell1Mv >= BALANCE_MIN_ANY_CELL_MV) || (cell2Mv >= BALANCE_MIN_ANY_CELL_MV);
  const uint16_t cellDiffMv =
      (cell1Mv >= cell2Mv) ? (uint16_t)(cell1Mv - cell2Mv) : (uint16_t)(cell2Mv - cell1Mv);
  const bool imbalanceEnough = cellDiffMv >= BALANCE_MIN_DELTA_MV;

  if (anyCellAboveMin && imbalanceEnough) {
    uint8_t balanceMask = 0x00;
    if (cell1Mv > cell2Mv) {
      balanceMask = 0x02; // bit1 = first active cell (VC1-VC0)
    } else if (cell2Mv > cell1Mv) {
      balanceMask = 0x04; // bit2 = second active cell
    }

    if (balanceMask != 0 &&
        (lastBalanceCommandMs == 0 || (uint16_t)(now - lastBalanceCommandMs) >= BALANCE_RETRIGGER_MS)) {
      writeConfig8(START_BALANCE, balanceMask);
      lastBalanceCommandMs = now;
    }
  }
}
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
void loop() {
  powerButtonTask();
#if ENABLE_SHIP_BUTTON
  shipButtonTask();
#endif
  hostBalanceTask();

  powerLedTask();
  batteryLedTask();
  debugStatusTask();
}

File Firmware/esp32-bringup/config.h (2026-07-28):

#pragma once

/**
 * Pin and bus configuration — adjust for your PCB before flashing.
 *
 * ESP32 has two hardware I2C peripherals (Wire instance 0 and 1).
 *
 * Bus roles (per Cyberdeck mainboard):
 * - BQ bus: BQ76905 (with ATtiny404) — pack monitor / protect IC.
 * - I2Ct: TPS25751 as I2C *target* — this is where the ESP talks to the PD controller
 *   for status (MODE, STATUS, PD, ADC, …). BQ25792 is monitored here as well (same
 *   net as in charger-monitor); you cannot use I2Cc for TPS access — that side is
 *   controller-only from the ESP.
 * - I2Cc: EEPROM (AT24) lives here *only* for factory flashing. The TPS must be
 *   powered down for this bus to be used safely / without clashing. Firmware
 *   temporarily remaps the second I2C peripheral from I2Ct pins to I2Cc pins only
 *   while an EEPROM job runs, then restores I2Ct for monitoring.
 */

#include <Arduino.h>

// Wi-Fi (replace or use WiFiManager later)
static const char *const WIFI_SSID = "Tangles";
static const char *const WIFI_PASS = "Jiblet!1337";

// --- I2C: BQ76905 + ATtiny404 host side ---
static const int PIN_I2C_BQ_SDA = 21;
static const int PIN_I2C_BQ_SCL = 22;
static const uint32_t I2C_BQ_HZ = 100000;
// Role handoff on the shared BQ76905 / ATtiny404 bus:
// - ESP starts as an I2C target at ESP_BQ_DISCOVERY_ADDR.
// - Tiny polls that address every few seconds while it owns the BQ.
// - Tiny sends BQ_ROLE_CMD_ESP_MASTER, switches to target mode at
//   TINY_BQ_COORDINATOR_ADDR, and the ESP becomes the BQ bus controller.
// - ESP pings the Tiny target; if either side loses the other, both fall back
//   to the safe state where the Tiny owns and reconfigures the BQ.
static const uint8_t ESP_BQ_DISCOVERY_ADDR = 0x42;
static const uint8_t TINY_BQ_COORDINATOR_ADDR = 0x43;
static const uint8_t BQ_ROLE_MAGIC = 0xC5;
static const uint8_t BQ_ROLE_CMD_ESP_MASTER = 0xA1;
static const uint8_t BQ_ROLE_CMD_TINY_PING = 0x5A;
static const bool ESP_BQ_ROLE_HANDOFF_ENABLED = false;
static const uint32_t BQ_ROLE_HANDOFF_SETTLE_MS = 500;
static const uint32_t BQ_ROLE_PING_PERIOD_MS = 500;
static const uint32_t BQ_ROLE_PING_TIMEOUT_MS = 1000;
static const uint32_t BQ_ROLE_FIRST_PING_GRACE_MS = 8000;

// --- I2Ct: TPS25751 (target) + BQ25792 — charger / PD monitoring ONLY ---
static const int PIN_I2C_I2CT_SDA = 18;
static const int PIN_I2C_I2CT_SCL = 19;
static const int PIN_I2C_I2CC_SDA = 25;
static const int PIN_I2C_I2CC_SCL = 26;
// static const int PIN_I2C_I2CT_SDA = 25;
// static const int PIN_I2C_I2CT_SCL = 26;
// static const int PIN_I2C_I2CC_SDA = 18;
// static const int PIN_I2C_I2CC_SCL = 19;
static const uint32_t I2C_I2CT_HZ = 400000;

// --- I2Cc: AT24 EEPROM — programming ONLY (power TPS down first) ---
static const uint32_t I2C_I2CC_HZ = 400000;

// --- ATtiny404 debug serial (BMS firmware DEBUG=1, TX-only on its PB2) ---
// Wire Tiny PB2 (BATT_LVL_2 net) -> this pin, plus common ground.
// RX-only; uses UART1 (UPDI owns UART2). Input-only pins 34/35 also work.
static const int PIN_TINY_DEBUG_RX = 27;
static const uint32_t TINY_DEBUG_BAUD = 115200;

// --- UPDI (ATtiny404 program flash) ---
// Match jtag2updi/SerialUPDI wiring:
//   ESP32 RX -> target UPDI directly
//   ESP32 TX -> target UPDI through a series resistor (typically 4.7k)
static const int PIN_UPDI_RX = 16;
static const int PIN_UPDI_TX = 17;
static const uint32_t UPDI_UART_BAUD = 115200;

// --- Device addresses ---
static const uint8_t BQ76905_ADDR = 0x08;
static const uint8_t BQ25792_ADDR = 0x6B;
static const uint8_t EEPROM_AT24_ADDR = 0x50;
static const uint8_t TPS25751_DEFAULT_ADDR = 0x22;
static const bool AUTO_DETECT_TPS25751 = true;

// TPS strap search order
static const uint8_t TPS25751_ADDR_CANDIDATES[] = {0x20, 0x21, 0x22, 0x23};

// EEPROM geometry (from eeprom-flasher sketch)
static const uint32_t EEPROM_SIZE_BYTES = 32768;
static const uint16_t EEPROM_PAGE_BYTES = 64;

// ATtiny404: 4 KB flash, 64-byte pages (tinyAVR 0-series; same UPDI layout as 202/402)
static const uint32_t ATTINY_FLASH_SIZE = 4096;
static const uint8_t ATTINY_FLASH_PAGE_SIZE = 64;
static const uint16_t ATTINY_FLASH_BYTE_BASE = 0x8000;

// megaTinyCore defaults for ATtiny404, 20 MHz internal, 8 ms startup, EEPROM retained.
// These mirror Upload Using Programmer / SerialUPDI fuse settings for the staged sketch.
static const bool ATTINY_WRITE_MEGA_TINY_CORE_FUSES = true;
static const uint8_t ATTINY_FUSE_WDTCFG = 0x00;
static const uint8_t ATTINY_FUSE_OSCCFG = 0x02;
static const uint8_t ATTINY_FUSE_SYSCFG0 = 0xC5;
static const uint8_t ATTINY_FUSE_SYSCFG1 = 0x04;
static const uint8_t ATTINY_FUSE_APPEND = 0x00;
static const uint8_t ATTINY_FUSE_BOOTEND = 0x00;

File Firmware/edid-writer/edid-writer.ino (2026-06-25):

#include <Arduino.h>
#include <WebServer.h>
#include <WiFi.h>
#include <Wire.h>

/*
  EDID writer for WEMOS D1 Mini ESP32.

  Wiring for a 24LC02B:
    ESP32 GPIO21/SDA -> EEPROM SDA
    ESP32 GPIO22/SCL -> EEPROM SCL
    3V3             -> EEPROM VCC, A0, A1, A2
    GND             -> EEPROM GND and WP for writing

  The sketch joins the configured Wi-Fi network and prints its IP address.
  It generates one base 128-byte EDID block, can download it as hex,
  and can flash/verify bytes 0x00-0x7f on an EEPROM responding at 0x50.
*/

static const char *WIFI_SSID = "Tangles";
static const char *WIFI_PASSWORD = "Jiblet!1337";
static const char *WIFI_HOSTNAME = "edid-writer";

static const uint8_t I2C_SDA_PIN = 21;
static const uint8_t I2C_SCL_PIN = 22;
static const uint8_t EEPROM_I2C_ADDR = 0x50;
static const uint8_t EEPROM_PAGE_SIZE = 8;
static const size_t EDID_SIZE = 128;
static const uint8_t MAX_TIMINGS = 4;

WebServer server(80);

struct EdidTiming {
  uint16_t hActive;
  uint16_t vActive;
  uint32_t pixelClockKHz;
  uint16_t hFrontPorch;
  uint16_t hSyncWidth;
  uint16_t hBackPorch;
  uint16_t vFrontPorch;
  uint16_t vSyncWidth;
  uint16_t vBackPorch;
  bool hSyncPositive;
  bool vSyncPositive;
};

struct EdidConfig {
  String manufacturer;
  String monitorName;
  uint16_t productCode;
  uint32_t serialNumber;
  uint8_t week;
  uint16_t year;
  uint8_t widthCm;
  uint8_t heightCm;
  uint8_t timingCount;
  EdidTiming timings[MAX_TIMINGS];
  uint8_t minRefreshHz;
  uint8_t maxRefreshHz;
  uint8_t minHorizontalKHz;
  uint8_t maxHorizontalKHz;
};

struct FlashJob {
  bool active;
  bool done;
  bool success;
  uint8_t progress;
  uint8_t state;
  size_t offset;
  unsigned long waitUntilMs;
  String message;
  uint8_t edid[EDID_SIZE];
};

FlashJob flashJob = {};

const char INDEX_HTML[] PROGMEM = R"rawliteral(
<!doctype html>
<html lang="en">
<head>
  <meta charset="utf-8">
  <meta name="viewport" content="width=device-width, initial-scale=1">
  <title>ESP32 EDID Writer</title>
  <style>
    :root {
      color-scheme: dark;
      --bg: #09111f;
      --card: #121c2d;
      --card2: #182438;
      --accent: #6ee7b7;
      --accent2: #60a5fa;
      --bad: #fb7185;
      --text: #e5eefc;
      --muted: #9db0ca;
      font-family: Inter, ui-sans-serif, system-ui, -apple-system, BlinkMacSystemFont, "Segoe UI", sans-serif;
    }
    * { box-sizing: border-box; }
    body {
      margin: 0;
      min-height: 100vh;
      background: radial-gradient(circle at top left, #1e3a5f 0, transparent 32rem), var(--bg);
      color: var(--text);
    }
    main { width: min(1120px, calc(100vw - 28px)); margin: 0 auto; padding: 28px 0 48px; }
    header { display: flex; justify-content: space-between; gap: 18px; align-items: flex-start; margin-bottom: 20px; }
    h1 { margin: 0; font-size: clamp(2rem, 6vw, 4rem); line-height: 0.95; letter-spacing: -0.06em; }
    h2 { margin: 0 0 16px; font-size: 1rem; color: var(--accent); letter-spacing: 0.08em; text-transform: uppercase; }
    p { color: var(--muted); line-height: 1.55; margin: 8px 0 0; }
    .pill {
      display: inline-flex;
      align-items: center;
      gap: 8px;
      border: 1px solid rgba(255,255,255,0.12);
      background: rgba(255,255,255,0.06);
      border-radius: 999px;
      padding: 10px 14px;
      white-space: nowrap;
      font-weight: 650;
    }
    .dot { width: 10px; height: 10px; border-radius: 999px; background: #f59e0b; box-shadow: 0 0 22px #f59e0b; }
    .ok .dot { background: var(--accent); box-shadow: 0 0 22px var(--accent); }
    .bad .dot { background: var(--bad); box-shadow: 0 0 22px var(--bad); }
    .grid { display: grid; grid-template-columns: repeat(12, 1fr); gap: 16px; }
    .card {
      grid-column: span 12;
      padding: 18px;
      border: 1px solid rgba(255,255,255,0.10);
      border-radius: 24px;
      background: linear-gradient(180deg, rgba(255,255,255,0.07), rgba(255,255,255,0.025)), var(--card);
      box-shadow: 0 20px 70px rgba(0,0,0,0.28);
    }
    .half { grid-column: span 6; }
    .third { grid-column: span 4; }
    .fields { display: grid; grid-template-columns: repeat(12, 1fr); gap: 12px; }
    label { display: grid; gap: 7px; grid-column: span 4; color: var(--muted); font-size: 0.82rem; font-weight: 650; }
    label.wide { grid-column: span 6; }
    .tabs {
      display: flex;
      flex-wrap: wrap;
      gap: 8px;
      align-items: center;
      margin-bottom: 14px;
    }
    .tab {
      border: 1px solid rgba(255,255,255,0.12);
      background: rgba(255,255,255,0.06);
      color: var(--text);
      padding: 9px 12px;
      border-radius: 999px;
      font-size: 0.9rem;
    }
    .tab.active {
      background: var(--accent);
      color: #06111f;
    }
    .timing-panel[hidden], .tab[hidden] { display: none; }
    input, select {
      width: 100%;
      border: 1px solid rgba(255,255,255,0.12);
      border-radius: 14px;
      background: var(--card2);
      color: var(--text);
      padding: 12px;
      font: inherit;
      outline: none;
    }
    input:focus, select:focus { border-color: var(--accent2); box-shadow: 0 0 0 3px rgba(96,165,250,0.18); }
    .actions { display: flex; flex-wrap: wrap; gap: 12px; align-items: center; margin-top: 16px; }
    button {
      border: 0;
      border-radius: 16px;
      padding: 13px 18px;
      color: #06111f;
      background: var(--accent);
      font: inherit;
      font-weight: 800;
      cursor: pointer;
    }
    button.secondary { background: var(--accent2); color: #07111f; }
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

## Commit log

2025-12-25 before M2 B key
    [cyberdeck-alpha.kicad_sch]
2026-01-02 BMS and USB-C 3.0 port complete
    [cyberdeck-alpha.kicad_sch]
2026-01-06 add firmware
    [cyberdeck-alpha.kicad_sch]
2026-01-06 charging circuit design
    [cyberdeck-alpha.kicad_sch]
2026-01-14 added power and charging to layout
    [cyberdeck-alpha.kicad_sch]
2026-01-14 add solder jumpers to MIPI DSI and length match traces
    [cyberdeck-alpha.kicad_sch]
2026-01-16 added solder jumpers for DSI and USB source (CM4 compatibility)
    [cyberdeck-alpha.kicad_sch]
2026-01-16 fix button part number
    [cyberdeck-alpha.kicad_sch]
2026-01-17 rename folder
    [FPC-SMD_22P-P1.00_AFC11-S22ICC-00.step, LED-ARRAY-SMD_3P-L3.0-W2.0-H1.0.step, SENSOR-SMD_TSOP77438TR.step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]
2026-01-20 add power module test board
    [FPC-SMD_22P-P1.00_AFC11-S22ICC-00.step, LED-ARRAY-SMD_3P-L3.0-W2.0-H1.0.step, SENSOR-SMD_TSOP77438TR.step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]
2026-01-29 add reference files for first revision
    [FPC-SMD_22P-P1.00_AFC11-S22ICC-00.step, LED-ARRAY-SMD_3P-L3.0-W2.0-H1.0.step, SENSOR-SMD_TSOP77438TR.step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]
2026-02-28 updates - need to clean up
    [cyberdeck-alpha.kicad_pcb, cyberdeck-alpha.kicad_sch]
2026-04-30 pcb updates
    [cyberdeck-alpha.kicad_pcb, cyberdeck-alpha.kicad_sch]
2026-05-01 add firmwares
    [cyberdeck-alpha.kicad_pcb, cyberdeck-alpha.kicad_sch]
2026-05-03 add \sketch for esp32 diagnostic / flashing jig, add tiny1604 BQ controller sketch
    [cyberdeck-alpha.kicad_pcb, cyberdeck-alpha.kicad_sch]
2026-05-12 controller updates
    [cyberdeck-alpha.kicad_pcb, cyberdeck-alpha.kicad_sch, rak4630-test.kicad_pcb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]
2026-06-08 work on PCB
    [cyberdeck-alpha.kicad_pcb, cyberdeck-alpha.kicad_sch]
2026-06-09 add footprints
2026-06-25 update firmware, add bringup sketch, organise PCB files
    [FPC-SMD_22P-P1.00_AFC11-S22ICC-00.step, LED-ARRAY-SMD_3P-L3.0-W2.0-H1.0.step, SENSOR-SMD_TSOP77438TR.step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]
2026-06-25 update repo structure
    [1-2199119-5.step, 1000base-t-magnetics.stp, 10164227-1001a1rlf.stp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]
2026-06-25 remove large models
    [board.step]
2026-06-25 added development PCB designs
    [display-driver.kicad_pcb, display-driver.kicad_sch, sound.kicad_pcb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]
2026-07-06 test usb 3 hub, test pwr regs v3
    [FPC-SMD_22P-P1.00_AFC11-S22ICC-00.step, LED-ARRAY-SMD_3P-L3.0-W2.0-H1.0.step, SENSOR-SMD_TSOP77438TR.step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]
2026-07-28 stuff and things
    [F32Q-1A7H1-11006--3DModel-STEP-56544.STEP, F32Q-1A7H1-11040--3DModel-STEP-56544.STEP, FPC-SMD_22P-P1.00_AFC11-S22ICC-00.step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]
